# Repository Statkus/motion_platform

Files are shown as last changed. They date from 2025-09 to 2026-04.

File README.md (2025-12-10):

# Motion platform

Motion platform for simracing and flight simulation

## Servo motor driver parameters

Pn001: 4
Pn002: 2
Pn003: 0
Pn008: 300
Pn009: -300
Pn024: 10
Pn051: 3000
Pn052: 1 or -1 depending of how emergency stop is wired
Pn060: 2
Pn061: 6
Pn098: 10
Pn109: 1
Pn110: 30
Pn113: 20
Pn114: 10
Pn115: 100

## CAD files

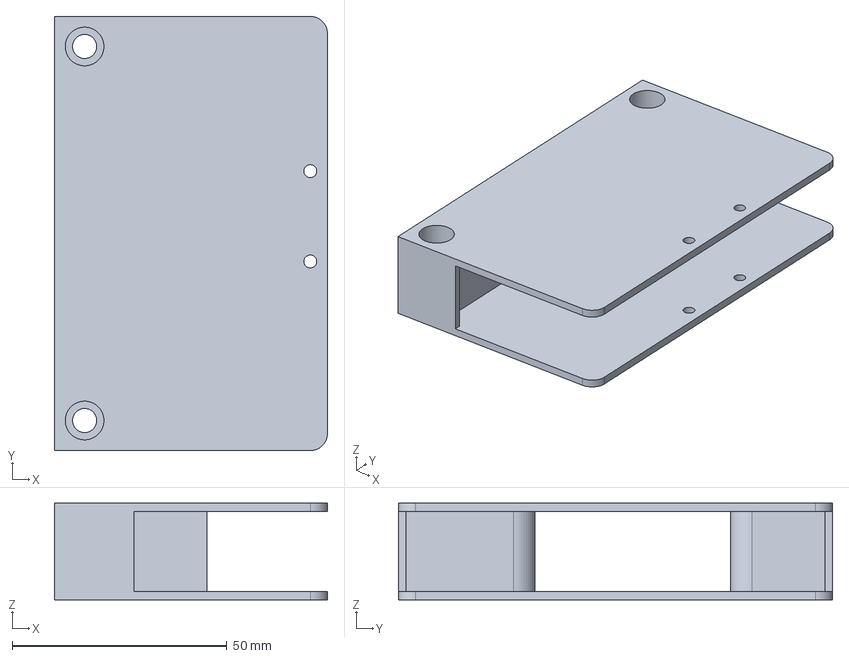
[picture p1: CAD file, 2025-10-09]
hardware/electrical_panel/main_breaker_mount.FCStd
63.5 x 101.0 x 22.5 mm

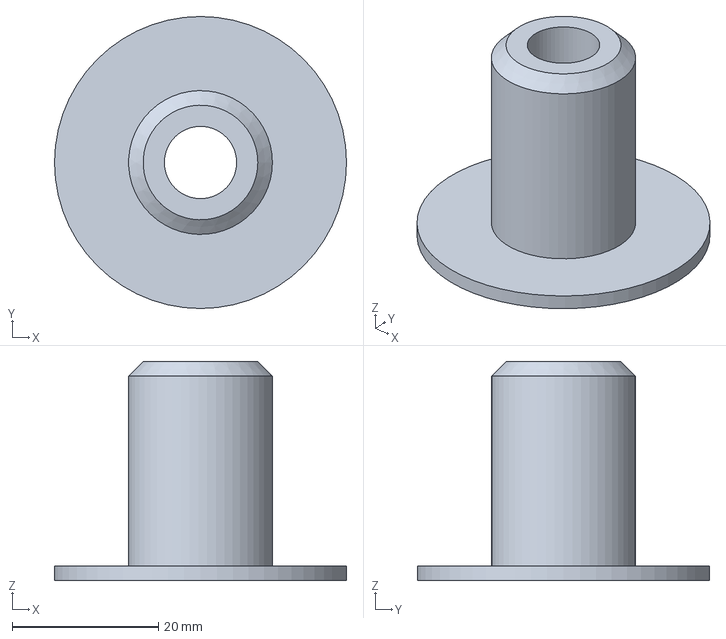
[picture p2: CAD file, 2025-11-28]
hardware/base_platform/3DOF_foot.FCStd
40.0 x 40.0 x 30.0 mm

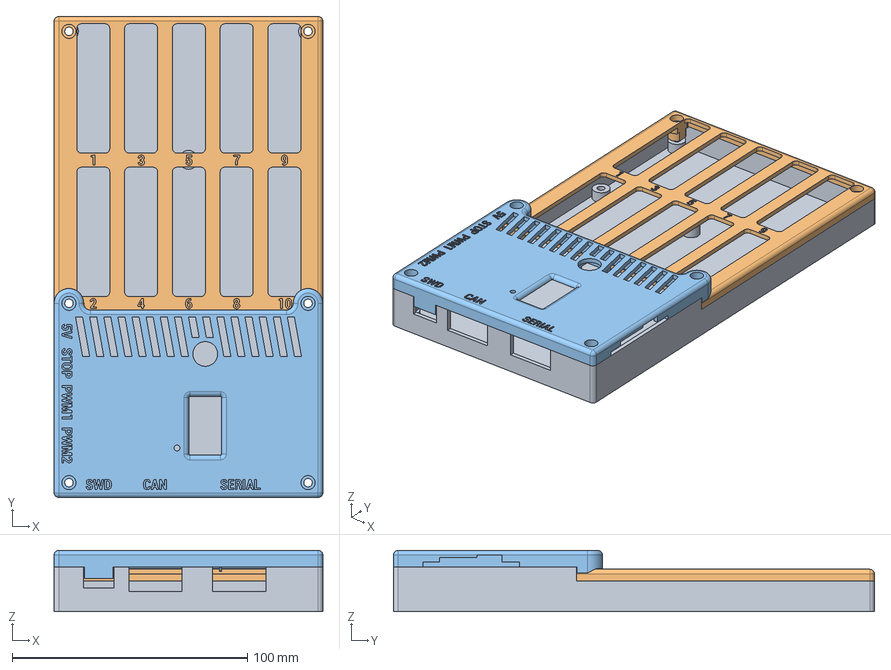
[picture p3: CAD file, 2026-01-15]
hardware/electrical_panel/control_box.FCStd
114.2 x 204.4 x 26.0 mm
Bottom
Top_DB25_text
Top_IC_text

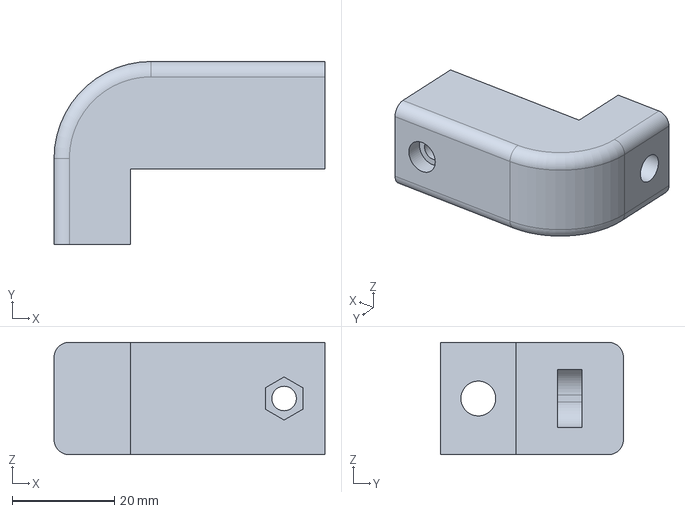
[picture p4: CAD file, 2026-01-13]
hardware/parts_library/pulley_to_SH25.FCStd
53.0 x 35.8 x 22.0 mm

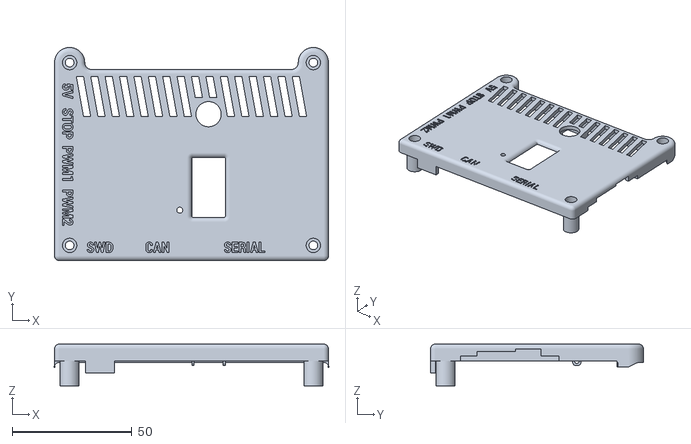
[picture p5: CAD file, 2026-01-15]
hardware/stl_files_to_print/control_box-Top_IC_text.stl
114.2 x 88.8 x 17.4

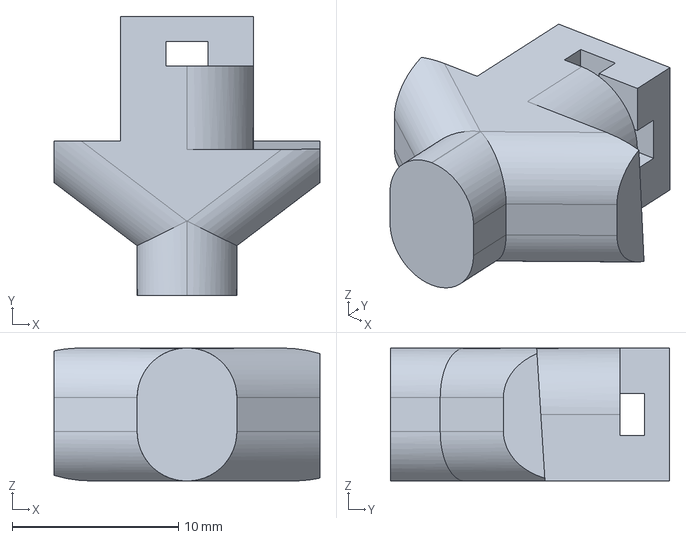
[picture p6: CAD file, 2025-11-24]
hardware/parts_library/zip_tie_2x1_mm_to_4040_profile.FCStd
16.0 x 16.8 x 8.00 mm

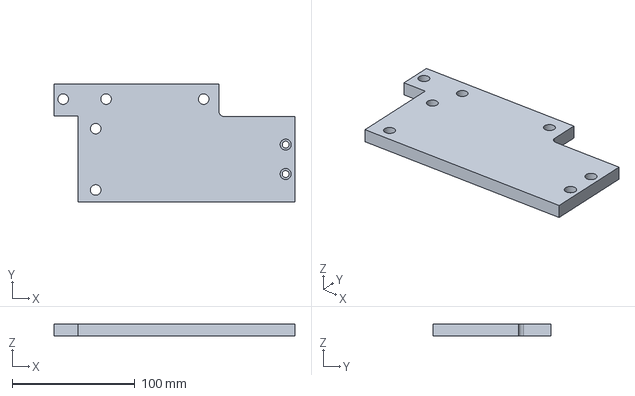
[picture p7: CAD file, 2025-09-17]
hardware/seat_mover/sway_motor_mount_rear_plate.FCStd
196.6 x 96.6 x 10.0 mm

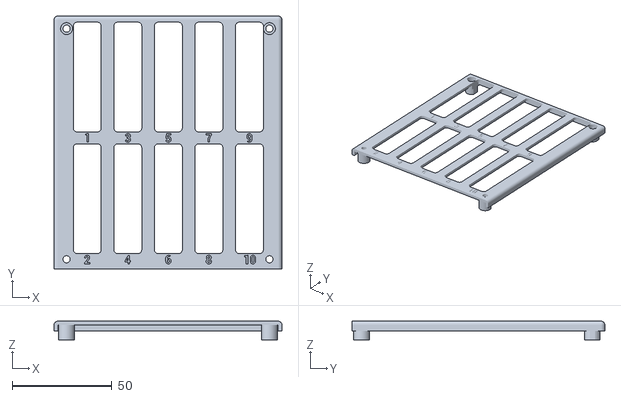
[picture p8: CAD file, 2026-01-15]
hardware/stl_files_to_print/control_box-Top_DB25_text.stl
114.2 x 126.7 x 9.40

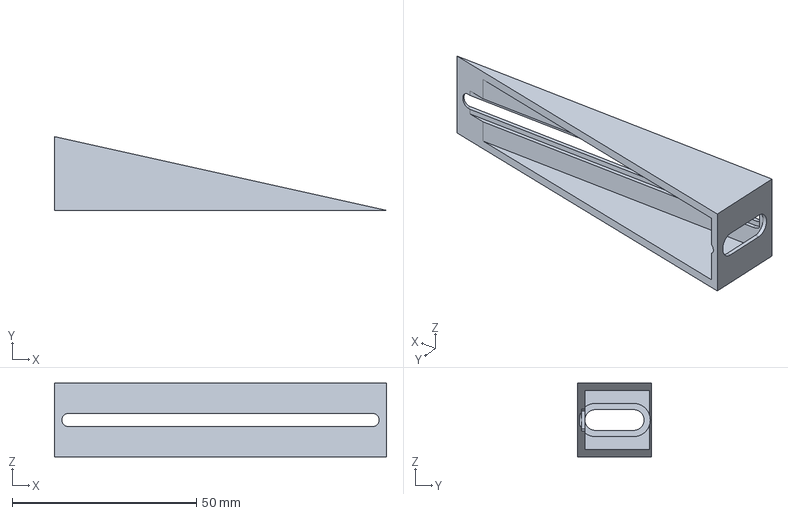
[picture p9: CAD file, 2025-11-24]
hardware/parts_library/2020_corner_bracket_M5_M3_long.FCStd
90.0 x 20.0 x 20.0 mm

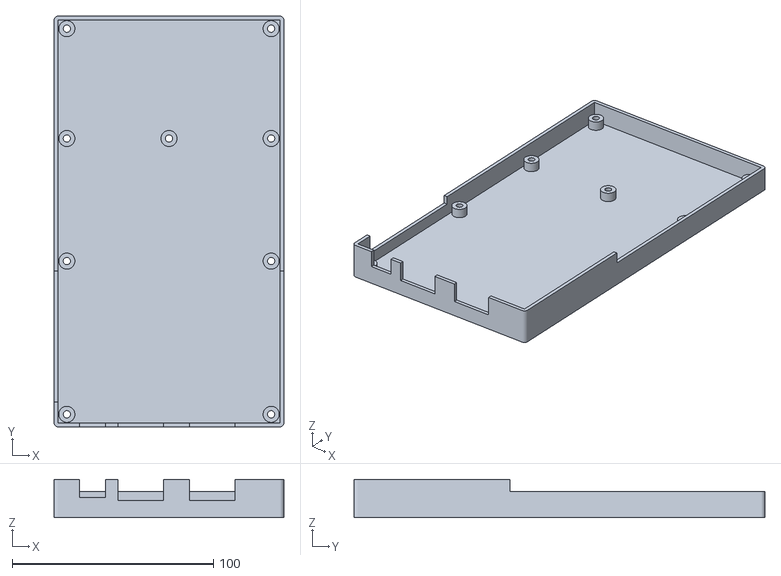
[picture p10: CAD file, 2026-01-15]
hardware/stl_files_to_print/control_box-Bottom.stl
114.2 x 204.4 x 19.0

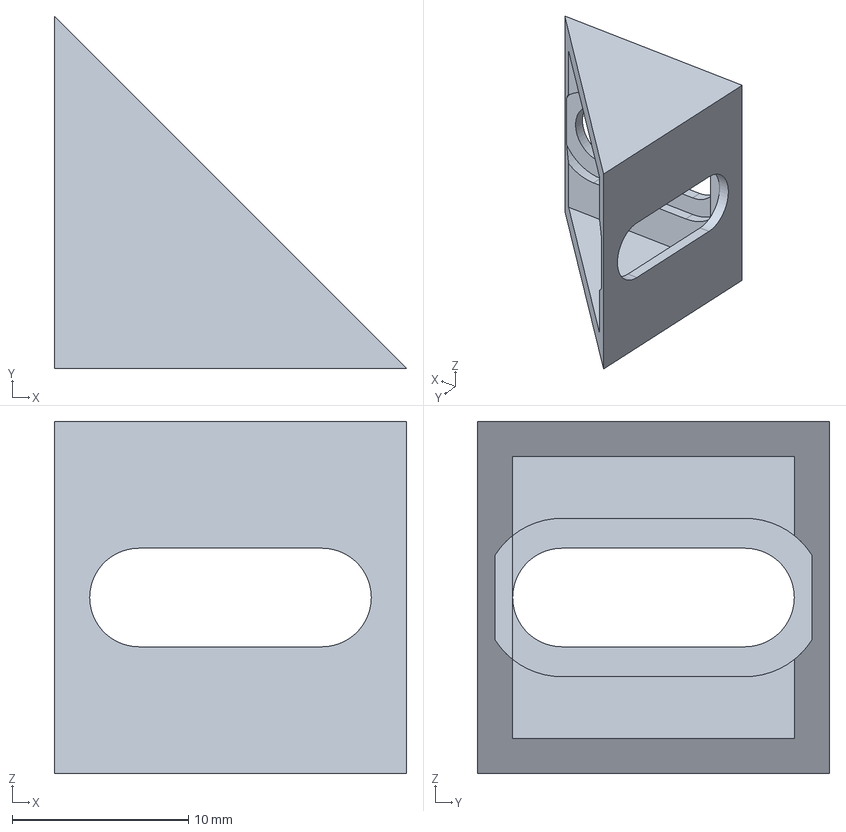
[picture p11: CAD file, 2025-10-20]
hardware/parts_library/2020_corner_bracket_M5.FCStd
20.0 x 20.0 x 20.0 mm

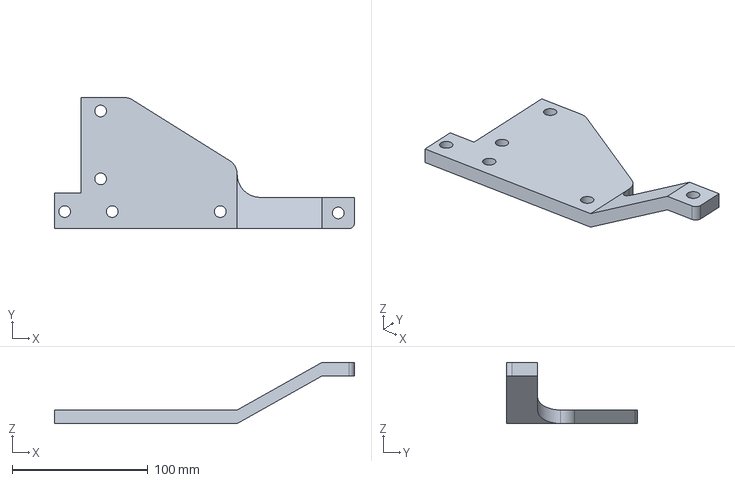
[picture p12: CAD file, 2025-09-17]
hardware/seat_mover/sway_motor_mount_front_plate.FCStd
221.0 x 96.6 x 45.0 mm

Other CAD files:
hardware/final_assembly.FCStd
hardware/stl_files_to_print/main_breaker_mount.stl
hardware/seat_mover/seat_mover.FCStd
hardware/base_platform/base_platform.FCStd
hardware/seat_mover/sway_platform.FCStd
hardware/stl_files_to_print/pulley_to_SH25.stl
hardware/parts_library/2020_corner_bracket_M5_M3.FCStd
hardware/parts_library/DSG16H_to_SH25.FCStd
hardware/parts_library/DSG16H_to_profile_40x40.FCStd
hardware/parts_library/SC25UU.FCStd
hardware/parts_library/SC25UU_to_SH25.FCStd
hardware/parts_library/SFU1605.FCStd
hardware/parts_library/SH25.FCStd
hardware/parts_library/SHF25.FCStd
hardware/parts_library/corner_bracket_40x40.FCStd
hardware/parts_library/coupler.FCStd
hardware/parts_library/linear_shaft.FCStd
hardware/parts_library/motor.FCStd
hardware/parts_library/profile_40_serie.FCStd
hardware/parts_library/zip_tie_2x1_mm_to_2020_profile.FCStd
hardware/seat_mover/seat.FCStd
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

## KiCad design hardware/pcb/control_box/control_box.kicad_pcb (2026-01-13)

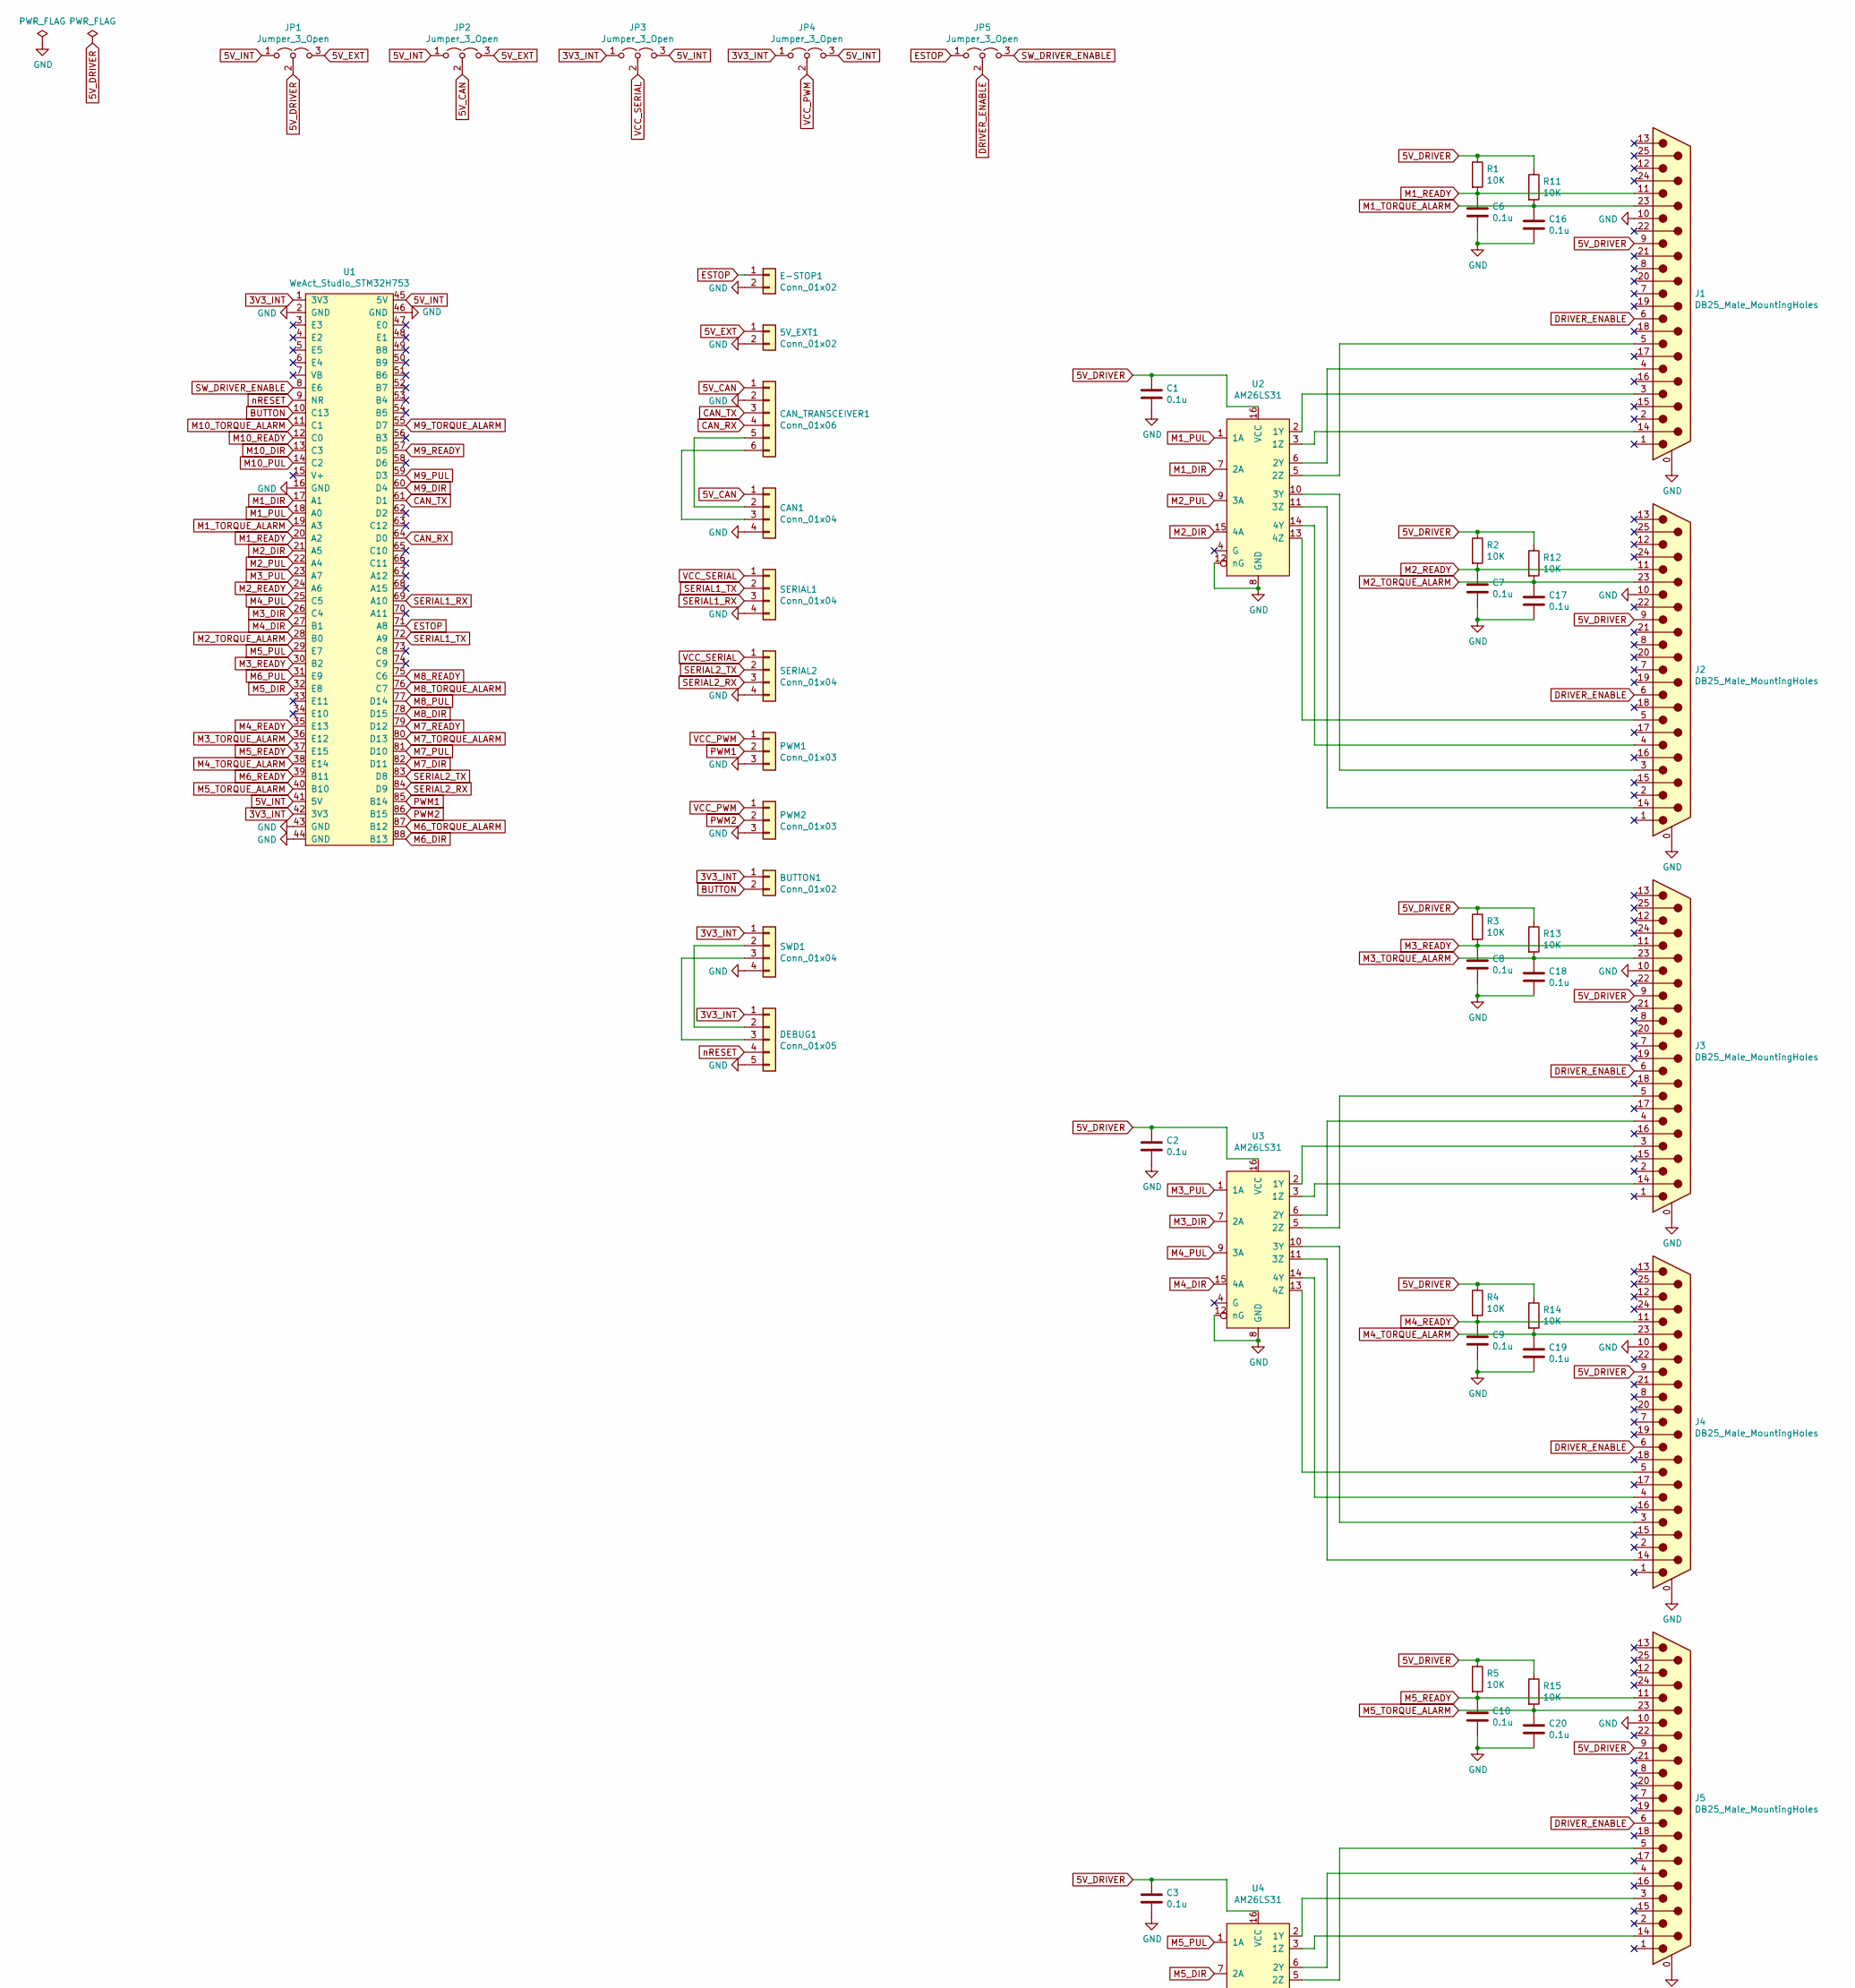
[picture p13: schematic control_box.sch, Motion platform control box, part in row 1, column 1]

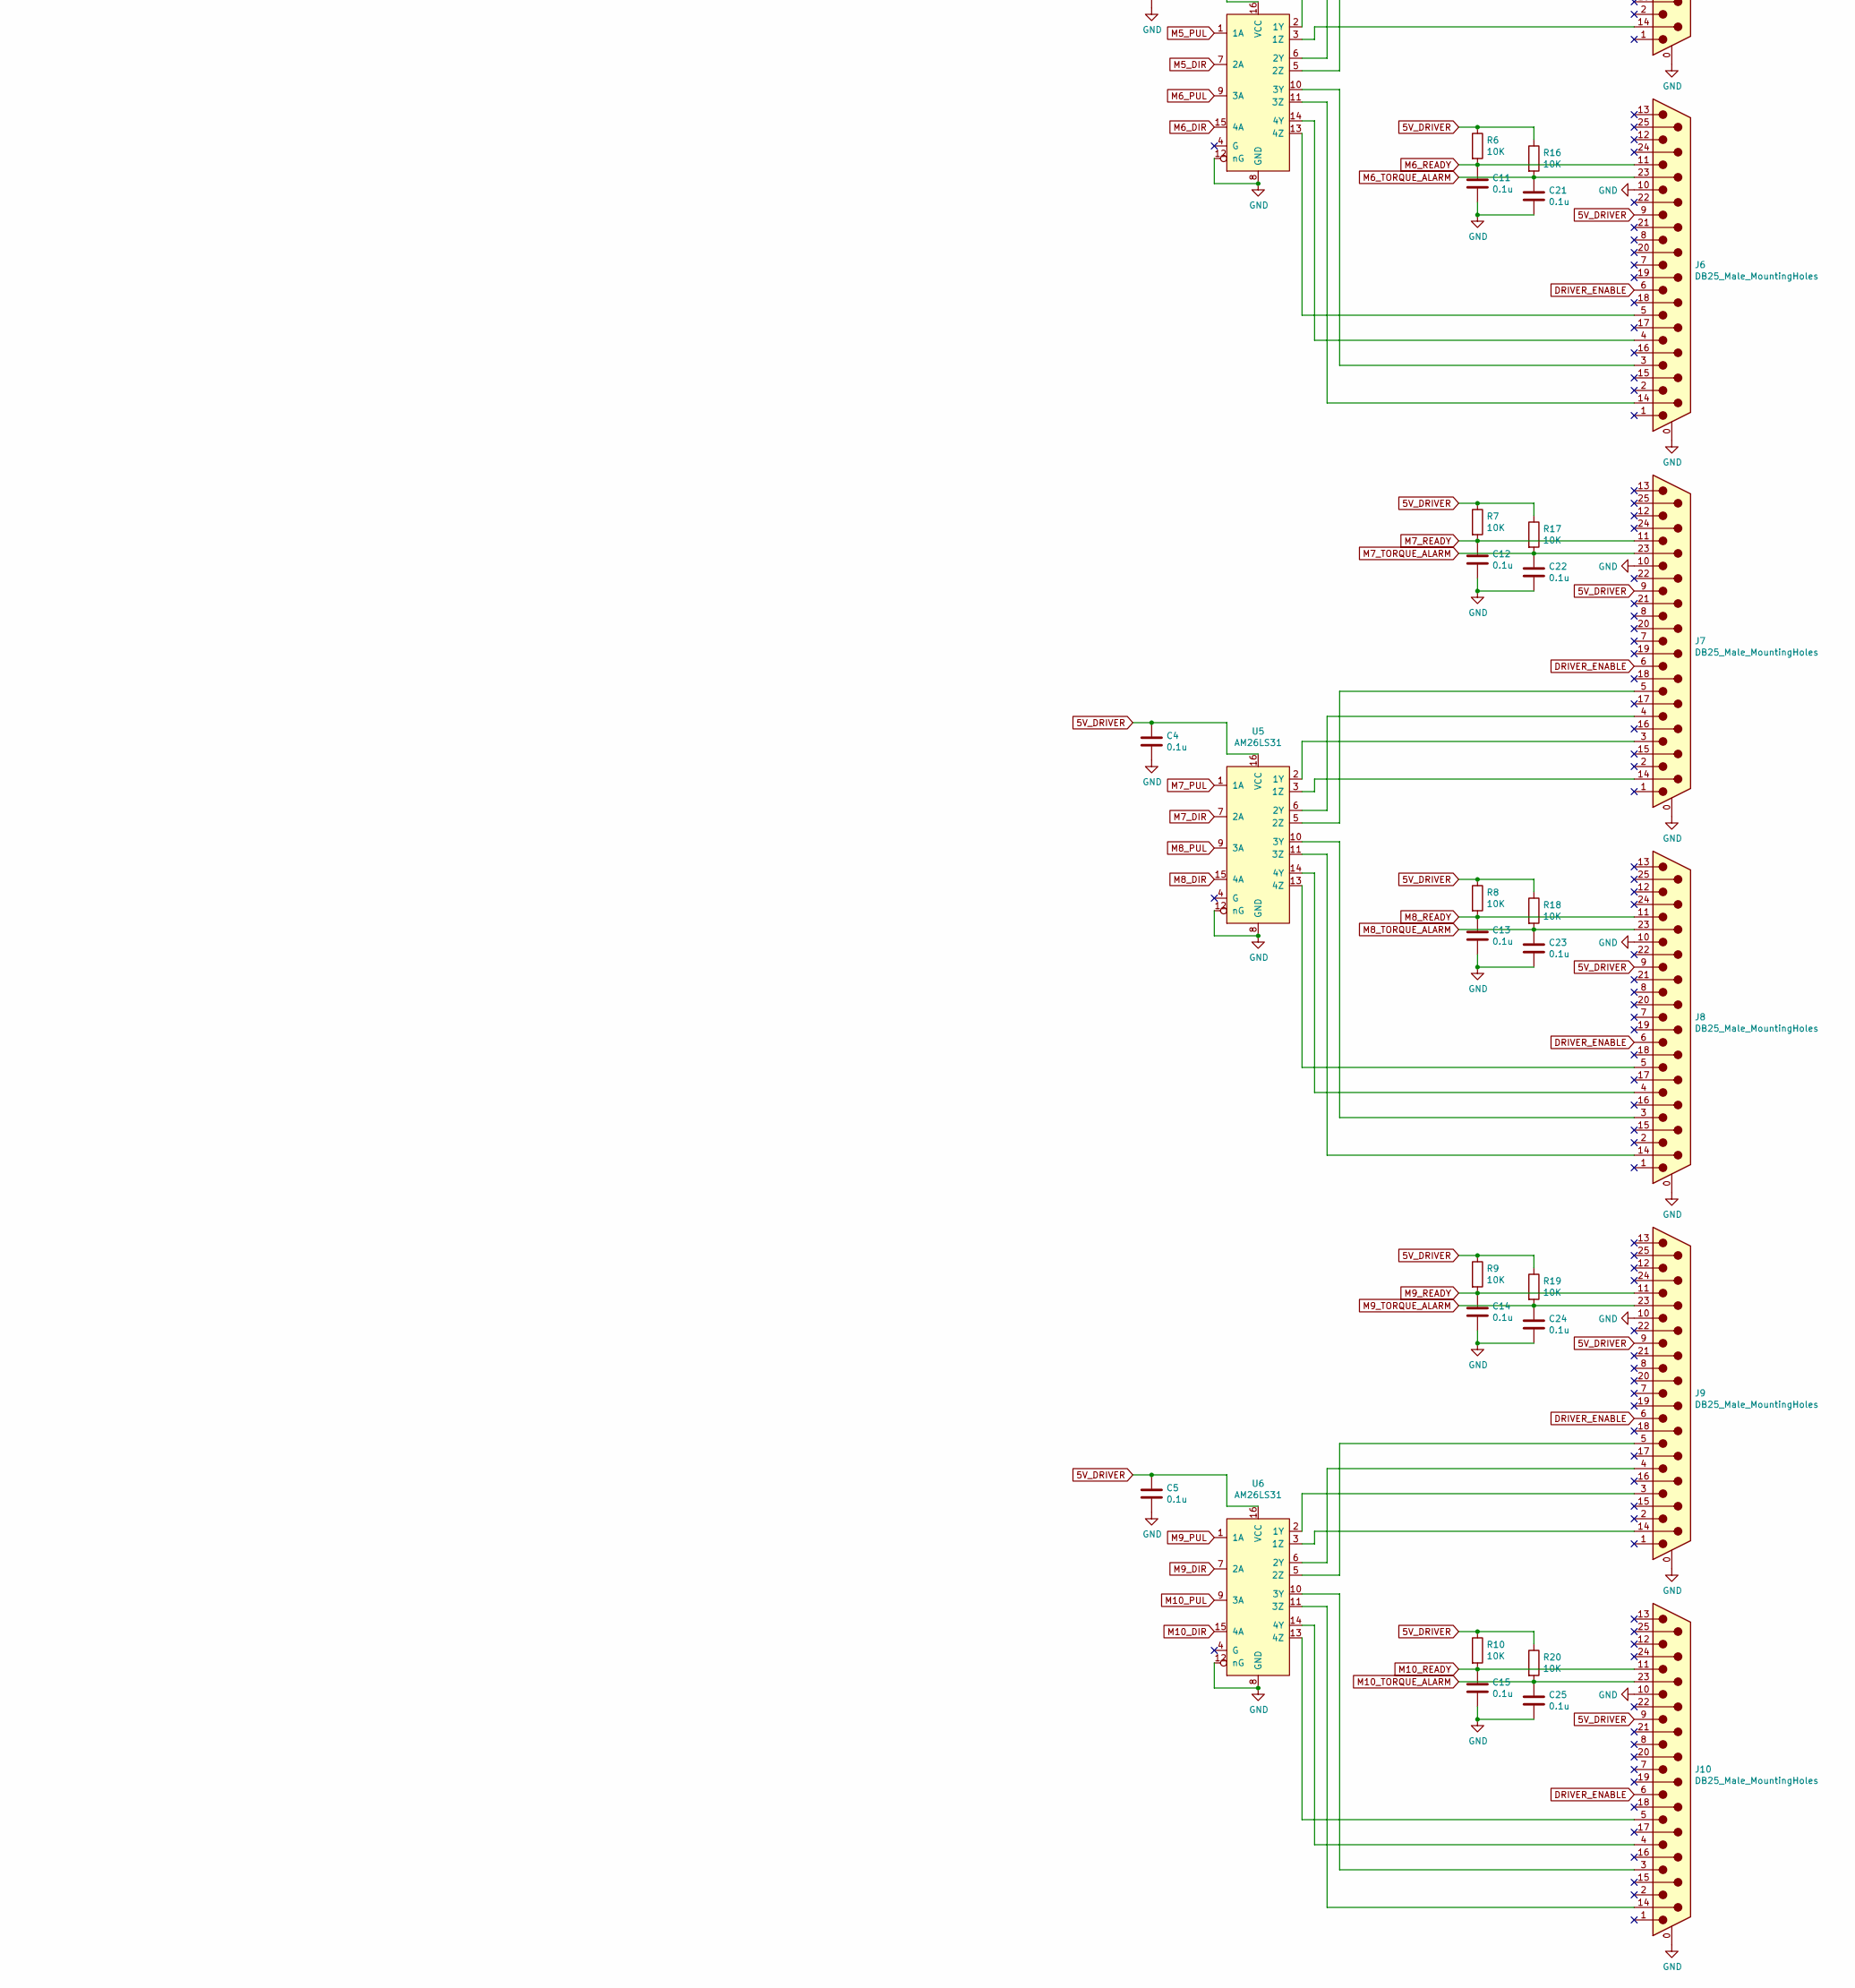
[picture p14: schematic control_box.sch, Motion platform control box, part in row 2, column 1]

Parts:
5V_EXT1: Conn_01x02; PhoenixContact_MSTBA_2,5_2-G-5,08_1x02_P5.08mm_Horizontal
BUTTON1: Conn_01x02; PinHeader_1x02_P2.54mm_Vertical
C1, C2, C3, C4, C5, C6, C7, C8, C9, C10, C11, C12, C13, C14, C15, C16, C17, C18, C19, C20, C21, C22, C23, C24, C25: 0.1u; C_Disc_D4.3mm_W1.9mm_P5.00mm
CAN1: Conn_01x04; PhoenixContact_MSTBA_2,5_4-G-5,08_1x04_P5.08mm_Horizontal
CAN_TRANSCEIVER1: Conn_01x06; PinHeader_1x06_P2.54mm_Vertical
DEBUG1: Conn_01x05; PinHeader_1x05_P2.54mm_Horizontal
E-STOP1: Conn_01x02; PhoenixContact_MSTBA_2,5_2-G-5,08_1x02_P5.08mm_Horizontal
J1, J2, J3, J4, J5, J6, J7, J8, J9, J10: DB25_Male_MountingHoles; DSUB-25_Female_Vertical_P2.77x2.84mm_MountingHoles
JP1, JP2, JP3, JP4, JP5: Jumper_3_Open; PinHeader_1x03_P2.54mm_Vertical
PWM1, PWM2: Conn_01x03; PhoenixContact_MSTBA_2,5_3-G-5,08_1x03_P5.08mm_Horizontal
R1, R2, R3, R4, R5, R6, R7, R8, R9, R10, R11, R12, R13, R14, R15, R16, R17, R18, R19, R20: 10K; R_Axial_DIN0204_L3.6mm_D1.6mm_P2.54mm_Vertical
SERIAL1: Conn_01x04; PinHeader_1x04_P2.54mm_Vertical
SERIAL2: Conn_01x04; PhoenixContact_MSTBA_2,5_4-G-5,08_1x04_P5.08mm_Horizontal
SWD1: Conn_01x04; PinHeader_1x04_P2.54mm_Vertical
U1: WeAct_Studio_STM32H753; WeAct_Studio_STM32H743
U2, U3, U4, U5, U6: AM26LS31; DIP-16_W7.62mm

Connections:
3V3_INT: BUTTON1.1, DEBUG1.1, JP3.1 (A), JP4.1 (A), SWD1.1, U1.1 (3V3), U1.42 (3V3)
5V_CAN: CAN1.1, CAN_TRANSCEIVER1.1, JP2.2 (C)
5V_DRIVER: C1.1, C2.1, C3.1, C4.1, C5.1, J1.9, J2.9, J3.9, J4.9, J5.9, J6.9, J7.9, J8.9, J9.9, J10.9, JP1.2 (C), R1.1, R2.1, R3.1, R4.1, R5.1, R6.1, R7.1, R8.1, R9.1, R10.1, R11.1, R12.1, R13.1, R14.1, R15.1, R16.1, R17.1, R18.1, R19.1, R20.1, U2.16 (VCC), U3.16 (VCC), U4.16 (VCC), U5.16 (VCC), U6.16 (VCC)
5V_EXT: 5V_EXT1.1, JP1.3 (B), JP2.3 (B)
5V_INT: JP1.1 (A), JP2.1 (A), JP3.3 (B), JP4.3 (B), U1.41 (5V), U1.45 (5V)
BUTTON: BUTTON1.2, U1.10 (C13)
CAN_RX: CAN_TRANSCEIVER1.4, U1.64 (D0)
CAN_TX: CAN_TRANSCEIVER1.3, U1.61 (D1)
DRIVER_ENABLE: J1.6, J2.6, J3.6, J4.6, J5.6, J6.6, J7.6, J8.6, J9.6, J10.6, JP5.2 (C)
ESTOP: E-STOP1.1, JP5.1 (A), U1.71 (A8)
GND: 5V_EXT1.2, C1.2, C2.2, C3.2, C4.2, C5.2, C6.2, C7.2, C8.2, C9.2, C10.2, C11.2, C12.2, C13.2, C14.2, C15.2, C16.2, C17.2, C18.2, C19.2, C20.2, C21.2, C22.2, C23.2, C24.2, C25.2, CAN1.4, CAN_TRANSCEIVER1.2, DEBUG1.5, E-STOP1.2, J1.0 (PAD), J1.10, J2.0 (PAD), J2.10, J3.0 (PAD), J3.10, J4.0 (PAD), J4.10, J5.0 (PAD), J5.10, J6.0 (PAD), J6.10, J7.0 (PAD), J7.10, J8.0 (PAD), J8.10, J9.0 (PAD), J9.10, J10.0 (PAD), J10.10, PWM1.3, PWM2.3, SERIAL1.4, SERIAL2.4, SWD1.4, U1.2 (GND), U1.16 (GND), U1.43 (GND), U1.44 (GND), U1.46 (GND), U2.8 (GND), U2.12 (nG), U3.8 (GND), U3.12 (nG), U4.8 (GND), U4.12 (nG), U5.8 (GND), U5.12 (nG), U6.8 (GND), U6.12 (nG)
M1_DIR: U1.17 (A1), U2.7 (2A)
M1_PUL: U1.18 (A0), U2.1 (1A)
M1_READY: C6.1, J1.11, R1.2, U1.20 (A2)
M1_TORQUE_ALARM: C16.1, J1.23, R11.2, U1.19 (A3)
M2_DIR: U1.21 (A5), U2.15 (4A)
M2_PUL: U1.22 (A4), U2.9 (3A)
M2_READY: C7.1, J2.11, R2.2, U1.24 (A6)
M2_TORQUE_ALARM: C17.1, J2.23, R12.2, U1.28 (B0)
M3_DIR: U1.26 (C4), U3.7 (2A)
M3_PUL: U1.23 (A7), U3.1 (1A)
M3_READY: C8.1, J3.11, R3.2, U1.30 (B2)
M3_TORQUE_ALARM: C18.1, J3.23, R13.2, U1.36 (E12)
M4_DIR: U1.27 (B1), U3.15 (4A)
M4_PUL: U1.25 (C5), U3.9 (3A)
M4_READY: C9.1, J4.11, R4.2, U1.35 (E13)
M4_TORQUE_ALARM: C19.1, J4.23, R14.2, U1.38 (E14)
M5_DIR: U1.32 (E8), U4.7 (2A)
M5_PUL: U1.29 (E7), U4.1 (1A)
M5_READY: C10.1, J5.11, R5.2, U1.37 (E15)
M5_TORQUE_ALARM: C20.1, J5.23, R15.2, U1.40 (B10)
M6_DIR: U1.88 (B13), U4.15 (4A)
M6_PUL: U1.31 (E9), U4.9 (3A)
M6_READY: C11.1, J6.11, R6.2, U1.39 (B11)
M6_TORQUE_ALARM: C21.1, J6.23, R16.2, U1.87 (B12)
M7_DIR: U1.82 (D11), U5.7 (2A)
M7_PUL: U1.81 (D10), U5.1 (1A)
M7_READY: C12.1, J7.11, R7.2, U1.79 (D12)
M7_TORQUE_ALARM: C22.1, J7.23, R17.2, U1.80 (D13)
M8_DIR: U1.78 (D15), U5.15 (4A)
M8_PUL: U1.77 (D14), U5.9 (3A)
M8_READY: C13.1, J8.11, R8.2, U1.75 (C6)
M8_TORQUE_ALARM: C23.1, J8.23, R18.2, U1.76 (C7)
M9_DIR: U1.60 (D4), U6.7 (2A)
M9_PUL: U1.59 (D3), U6.1 (1A)
M9_READY: C14.1, J9.11, R9.2, U1.57 (D5)
M9_TORQUE_ALARM: C24.1, J9.23, R19.2, U1.55 (D7)
M10_DIR: U1.13 (C3), U6.15 (4A)
M10_PUL: U1.14 (C2), U6.9 (3A)
M10_READY: C15.1, J10.11, R10.2, U1.12 (C0)
M10_TORQUE_ALARM: C25.1, J10.23, R20.2, U1.11 (C1)
unnamed: CAN1.2, CAN_TRANSCEIVER1.5
unnamed: CAN1.3, CAN_TRANSCEIVER1.6
unnamed: DEBUG1.2, SWD1.2
unnamed: DEBUG1.3, SWD1.3
unnamed: J1.3, U2.2 (1Y)
unnamed: J1.4, U2.6 (2Y)
unnamed: J1.5, U2.5 (2Z)
unnamed: J1.14, U2.3 (1Z)
unnamed: J2.3, U2.10 (3Y)
unnamed: J2.4, U2.14 (4Y)
unnamed: J2.5, U2.13 (4Z)
unnamed: J2.14, U2.11 (3Z)
unnamed: J3.3, U3.2 (1Y)
unnamed: J3.4, U3.6 (2Y)
unnamed: J3.5, U3.5 (2Z)
unnamed: J3.14, U3.3 (1Z)
unnamed: J4.3, U3.10 (3Y)
unnamed: J4.4, U3.14 (4Y)
unnamed: J4.5, U3.13 (4Z)
unnamed: J4.14, U3.11 (3Z)
unnamed: J5.3, U4.2 (1Y)
unnamed: J5.4, U4.6 (2Y)
unnamed: J5.5, U4.5 (2Z)
unnamed: J5.14, U4.3 (1Z)
unnamed: J6.3, U4.10 (3Y)
unnamed: J6.4, U4.14 (4Y)
unnamed: J6.5, U4.13 (4Z)
unnamed: J6.14, U4.11 (3Z)
unnamed: J7.3, U5.2 (1Y)
unnamed: J7.4, U5.6 (2Y)
unnamed: J7.5, U5.5 (2Z)
unnamed: J7.14, U5.3 (1Z)
unnamed: J8.3, U5.10 (3Y)
unnamed: J8.4, U5.14 (4Y)
unnamed: J8.5, U5.13 (4Z)
unnamed: J8.14, U5.11 (3Z)
unnamed: J9.3, U6.2 (1Y)
unnamed: J9.4, U6.6 (2Y)
unnamed: J9.5, U6.5 (2Z)
unnamed: J9.14, U6.3 (1Z)
unnamed: J10.3, U6.10 (3Y)
unnamed: J10.4, U6.14 (4Y)
unnamed: J10.5, U6.13 (4Z)
unnamed: J10.14, U6.11 (3Z)
PWM1: PWM1.2, U1.85 (B14)
PWM2: PWM2.2, U1.86 (B15)
SERIAL1_RX: SERIAL1.3, U1.69 (A10)
SERIAL1_TX: SERIAL1.2, U1.72 (A9)
SERIAL2_RX: SERIAL2.3, U1.84 (D9)
SERIAL2_TX: SERIAL2.2, U1.83 (D8)
SW_DRIVER_ENABLE: JP5.3 (B), U1.8 (E6)
VCC_PWM: JP4.2 (C), PWM1.1, PWM2.1
VCC_SERIAL: JP3.2 (C), SERIAL1.1, SERIAL2.1
nRESET: DEBUG1.4, U1.9 (NR)

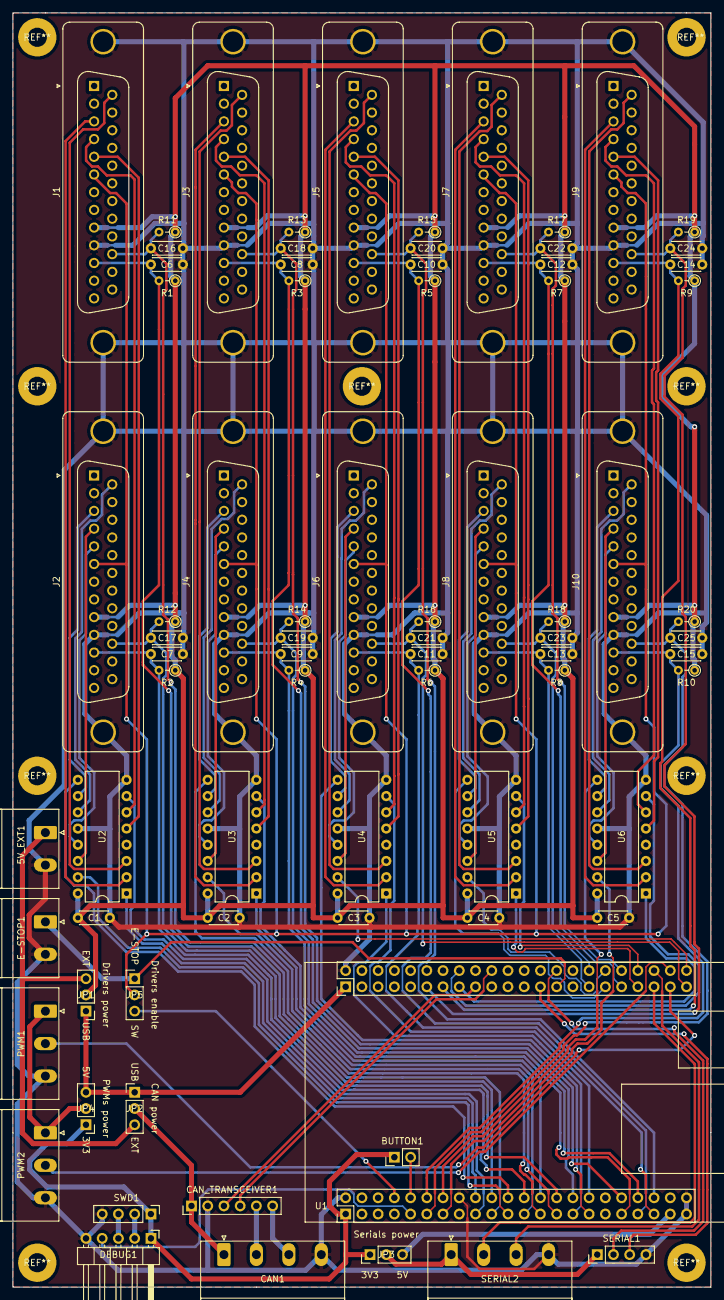
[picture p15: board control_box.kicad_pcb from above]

Board: 2 copper layers, 109.2 x 199.4 mm, 77 parts (0 on the bottom side), 105 nets.

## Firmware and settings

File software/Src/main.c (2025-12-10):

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
/* Includes ------------------------------------------------------------------*/
#include "main.h"
#include "usb_device.h"

/* USER CODE BEGIN Includes */

#include "motion_platform_configuration.h"
#include "usbd_cdc_if.h"

/* USER CODE END Includes */

/* USER CODE BEGIN PTD */

typedef struct
{
  GPIO_TypeDef *Port;
  uint16_t Pin;
} GPIO;

typedef struct
{
  GPIO Pulse_GPIO;
  GPIO Direction_GPIO;
  GPIO Ready_GPIO;
  GPIO Torque_Alarm_GPIO;

  int32_t Position;
  uint8_t Position_Zero_Centered;
  int32_t Min_Position;
  int32_t Max_Position;
  int32_t Target_Position;
  GPIO_PinState Direction;

  uint8_t Needs_Calibration;
  uint8_t Min_Position_Calibrated;
  uint8_t Max_Position_Calibrated;
} Motor;

typedef enum
{
  Initialization,
  Calibrate_Min_Position,
  Calibrate_Max_Position,
  Run
} State;

/* USER CODE END PTD */


TIM_HandleTypeDef htim3;
TIM_HandleTypeDef htim12;

/* USER CODE BEGIN PV */

Motor motors[NB_MOTORS] = {
  /* Motor 1 -----------------------------------------------------------------*/
  {.Pulse_GPIO =
    {.Port = M1_PUL_GPIO_Port,
     .Pin  = M1_PUL_Pin},
   .Direction_GPIO =
    {.Port = M1_DIR_GPIO_Port,
     .Pin  = M1_DIR_Pin},
   .Ready_GPIO =
    {.Port = M1_READY_GPIO_Port,
     .Pin  = M1_READY_Pin},
   .Torque_Alarm_GPIO =
    {.Port = M1_TORQUE_ALARM_GPIO_Port,
     .Pin  = M1_TORQUE_ALARM_Pin},

   .Position               = 0,
   .Position_Zero_Centered = M1_POSITION_ZERO_CENTERED,
   .Min_Position           = M1_MIN_POSITION,
   .Max_Position           = M1_MAX_POSITION,
   .Target_Position        = 0,
   .Direction              = GPIO_PIN_RESET,

   .Needs_Calibration       = M1_NEEDS_CALIBRATION,
   .Min_Position_Calibrated = 0,
   .Max_Position_Calibrated = 0},

  /* Motor 2 -----------------------------------------------------------------*/
  {.Pulse_GPIO =
    {.Port = M2_PUL_GPIO_Port,
     .Pin  = M2_PUL_Pin},
   .Direction_GPIO =
    {.Port = M2_DIR_GPIO_Port,
     .Pin  = M2_DIR_Pin},
   .Ready_GPIO =
    {.Port = M2_READY_GPIO_Port,
     .Pin  = M2_READY_Pin},
   .Torque_Alarm_GPIO =
    {.Port = M2_TORQUE_ALARM_GPIO_Port,
     .Pin  = M2_TORQUE_ALARM_Pin},

   .Position               = 0,
   .Position_Zero_Centered = M2_POSITION_ZERO_CENTERED,
   .Min_Position           = M2_MIN_POSITION,
   .Max_Position           = M2_MAX_POSITION,
   .Target_Position        = 0,
   .Direction              = GPIO_PIN_RESET,

   .Needs_Calibration       = M2_NEEDS_CALIBRATION,
   .Min_Position_Calibrated = 0,
   .Max_Position_Calibrated = 0},

  /* Motor 3 -----------------------------------------------------------------*/
  {.Pulse_GPIO =
    {.Port = M3_PUL_GPIO_Port,
     .Pin  = M3_PUL_Pin},
   .Direction_GPIO =
    {.Port = M3_DIR_GPIO_Port,
     .Pin  = M3_DIR_Pin},
   .Ready_GPIO =
    {.Port = M3_READY_GPIO_Port,
     .Pin  = M3_READY_Pin},
   .Torque_Alarm_GPIO =
    {.Port = M3_TORQUE_ALARM_GPIO_Port,
     .Pin  = M3_TORQUE_ALARM_Pin},

   .Position               = 0,
   .Position_Zero_Centered = M3_POSITION_ZERO_CENTERED,
   .Min_Position           = M3_MIN_POSITION,
   .Max_Position           = M3_MAX_POSITION,
   .Target_Position        = 0,
   .Direction              = GPIO_PIN_RESET,

   .Needs_Calibration       = M3_NEEDS_CALIBRATION,
   .Min_Position_Calibrated = 0,
   .Max_Position_Calibrated = 0},

  /* Motor 4 -----------------------------------------------------------------*/
  {.Pulse_GPIO =
    {.Port = M4_PUL_GPIO_Port,
     .Pin  = M4_PUL_Pin},
   .Direction_GPIO =
    {.Port = M4_DIR_GPIO_Port,
     .Pin  = M4_DIR_Pin},
   .Ready_GPIO =
    {.Port = M4_READY_GPIO_Port,
     .Pin  = M4_READY_Pin},
   .Torque_Alarm_GPIO =
    {.Port = M4_TORQUE_ALARM_GPIO_Port,
     .Pin  = M4_TORQUE_ALARM_Pin},

   .Position               = 0,
   .Position_Zero_Centered = M4_POSITION_ZERO_CENTERED,
   .Min_Position           = M4_MIN_POSITION,
   .Max_Position           = M4_MAX_POSITION,
   .Target_Position        = 0,
   .Direction              = GPIO_PIN_RESET,

   .Needs_Calibration       = M4_NEEDS_CALIBRATION,
   .Min_Position_Calibrated = 0,
   .Max_Position_Calibrated = 0},

  /* Motor 5 -----------------------------------------------------------------*/
  {.Pulse_GPIO =
    {.Port = M5_PUL_GPIO_Port,
     .Pin  = M5_PUL_Pin},
   .Direction_GPIO =
    {.Port = M5_DIR_GPIO_Port,
     .Pin  = M5_DIR_Pin},
   .Ready_GPIO =
    {.Port = M5_READY_GPIO_Port,
     .Pin  = M5_READY_Pin},
   .Torque_Alarm_GPIO =
    {.Port = M5_TORQUE_ALARM_GPIO_Port,
     .Pin  = M5_TORQUE_ALARM_Pin},

   .Position               = 0,
   .Position_Zero_Centered = M5_POSITION_ZERO_CENTERED,
   .Min_Position           = M5_MIN_POSITION,
   .Max_Position           = M5_MAX_POSITION,
   .Target_Position        = 0,
   .Direction              = GPIO_PIN_RESET,

   .Needs_Calibration       = M5_NEEDS_CALIBRATION,
   .Min_Position_Calibrated = 0,
   .Max_Position_Calibrated = 0},

  /* Motor 6 -----------------------------------------------------------------*/
  {.Pulse_GPIO =
    {.Port = M6_PUL_GPIO_Port,
     .Pin  = M6_PUL_Pin},
   .Direction_GPIO =
    {.Port = M6_DIR_GPIO_Port,
     .Pin  = M6_DIR_Pin},
   .Ready_GPIO =
    {.Port = M6_READY_GPIO_Port,
     .Pin  = M6_READY_Pin},
   .Torque_Alarm_GPIO =
    {.Port = M6_TORQUE_ALARM_GPIO_Port,
     .Pin  = M6_TORQUE_ALARM_Pin},

   .Position               = 0,
   .Position_Zero_Centered = M6_POSITION_ZERO_CENTERED,
   .Min_Position           = M6_MIN_POSITION,
   .Max_Position           = M6_MAX_POSITION,
   .Target_Position        = 0,
   .Direction              = GPIO_PIN_RESET,

   .Needs_Calibration       = M6_NEEDS_CALIBRATION,
   .Min_Position_Calibrated = 0,
   .Max_Position_Calibrated = 0},
};

int32_t m_speed        = 0; // step/s
int32_t m_target_speed = 0; // step/s

/* USER CODE END PV */

void SystemClock_Config(void);
static void MPU_Config(void);
static void MX_GPIO_Init(void);
static void MX_TIM3_Init(void);
static void MX_TIM12_Init(void);
/* USER CODE BEGIN PFP */

void Receive_Commands(void);
void Move_Motors_To_Min_Position(void);
void Move_Motors_To_Max_Position(void);
void Move_Motors_To_Target(void);
void Delay_Us(uint16_t us);

/* USER CODE END PFP */

/**
  * @brief  The application entry point.
  * @retval int
  */
int main(void)
{

  /* MPU Configuration--------------------------------------------------------*/
  MPU_Config();

  /* MCU Configuration--------------------------------------------------------*/

  /* Reset of all peripherals, Initializes the Flash interface and the Systick. */
  HAL_Init();

  /* Configure the system clock */
  SystemClock_Config();

  /* Initialize all configured peripherals */
  MX_GPIO_Init();
  MX_TIM3_Init();
  MX_USB_DEVICE_Init();
  MX_TIM12_Init();
  /* USER CODE BEGIN 2 */

  State state = Initialization;

  for (int i = 0; i < NB_MOTORS; i++) {
    motors[i].Direction = GPIO_PIN_RESET;

    HAL_GPIO_WritePin(motors[i].Pulse_GPIO.Port, motors[i].Pulse_GPIO.Pin, GPIO_PIN_SET);
    HAL_GPIO_WritePin(motors[i].Direction_GPIO.Port, motors[i].Direction_GPIO.Pin, motors[i].Direction);
  }

  HAL_TIM_Base_Start(&htim3);

  HAL_TIM_PWM_Start(&htim12, TIM_CHANNEL_1);
  HAL_TIM_PWM_Start(&htim12, TIM_CHANNEL_2);

  __HAL_TIM_SET_COMPARE(&htim12, TIM_CHANNEL_1, 500);
  __HAL_TIM_SET_COMPARE(&htim12, TIM_CHANNEL_2, 0);

  /* USER CODE END 2 */

  /* Infinite loop */
  /* USER CODE BEGIN WHILE */
  while (1)
  {
    /* USER CODE END WHILE */

    /* USER CODE BEGIN 3 */

    switch (state)
    {
      case Initialization:
      {
        uint8_t motors_ready = 1;

        for (int i = 0; i < NB_MOTORS; i++)
        {
          if (HAL_GPIO_ReadPin(motors[i].Ready_GPIO.Port, motors[i].Ready_GPIO.Pin) == GPIO_PIN_SET)
          {
            motors_ready = 0;
          }
        }

        if (motors_ready > 0)
        {
          HAL_GPIO_WritePin(LED_GPIO_Port, LED_Pin, GPIO_PIN_SET);

          if (HAL_GPIO_ReadPin(BUTTON_GPIO_Port, BUTTON_Pin) == GPIO_PIN_SET)
          {
            state = Calibrate_Min_Position;
            HAL_GPIO_WritePin(LED_GPIO_Port, LED_Pin, GPIO_PIN_RESET);
          }
        }
        else
        {
          HAL_GPIO_WritePin(LED_GPIO_Port, LED_Pin, GPIO_PIN_RESET);
        }

        break;
      }

      case Calibrate_Min_Position:
      {
        uint8_t needs_calibration = 0;

        for (int i = 0; i < NB_MOTORS; i++)
        {
          if (motors[i].Needs_Calibration > 0 && motors[i].Min_Position_Calibrated == 0)
          {
            if (HAL_GPIO_ReadPin(motors[i].Torque_Alarm_GPIO.Port, motors[i].Torque_Alarm_GPIO.Pin) == GPIO_PIN_RESET)
            {
              motors[i].Min_Position_Calibrated = 1;
              motors[i].Position                = 0;
              motors[i].Min_Position            = MIN_MAX_SAFETY_BUFFER;
              motors[i].Target_Position         = motors[i].Min_Position;
            }
            else
            {
              needs_calibration = 1;
            }
          }
        }

        if (needs_calibration > 0)
        {
          Move_Motors_To_Min_Position();
        }
        else
        {
          state = Calibrate_Max_Position;
        }

        break;
      }

      case Calibrate_Max_Position:
      {
        uint8_t needs_calibration = 0;

        for (int i = 0; i < NB_MOTORS; i++)
        {
          if (motors[i].Needs_Calibration > 0 && motors[i].Max_Position_Calibrated == 0)
          {
            if (HAL_GPIO_ReadPin(motors[i].Torque_Alarm_GPIO.Port, motors[i].Torque_Alarm_GPIO.Pin) == GPIO_PIN_RESET && motors[i].Position > motors[i].Min_Position)
            {
              motors[i].Max_Position_Calibrated = 1;
              motors[i].Max_Position            = motors[i].Position - MIN_MAX_SAFETY_BUFFER;

              if (motors[i].Position_Zero_Centered > 0)
              {
                motors[i].Min_Position    = (motors[i].Min_Position - motors[i].Max_Position) / 2;
                motors[i].Max_Position    = -motors[i].Min_Position;
                motors[i].Position        = motors[i].Max_Position + MIN_MAX_SAFETY_BUFFER;

                motors[i].Target_Position = 0;
              }
              else
              {
                motors[i].Target_Position = (motors[i].Max_Position - motors[i].Min_Position) / 2;
              }

              m_target_speed = M_MAX_SPEED / 2;
            }
            else
            {
              needs_calibration = 1;
            }
          }
        }

        if (needs_calibration > 0)
        {
          Move_Motors_To_Max_Position();
        }
        else
        {
          HAL_GPIO_WritePin(LED_GPIO_Port, LED_Pin, GPIO_PIN_SET);

          state = Run;
        }

        break;
      }

      case Run:
        Receive_Commands();

        Move_Motors_To_Target();

        break;
    }
  }
  /* USER CODE END 3 */
}

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
/* USER CODE BEGIN 4 */

void Receive_Commands(void)
{
  if (Is_New_Data() > 0)
  {
    HAL_GPIO_TogglePin(LED_GPIO_Port, LED_Pin);

    int32_t pos_target = 0;
    int32_t dist       = 0;
    int32_t max_dist   = 0;

    for (int i = 0; i < NB_MOTORS; i++)
    {
      pos_target = Get_M_Pos_Target(i);

      if (motors[i].Position_Zero_Centered > 0)
      {
        pos_target -= 32767;
      }

      motors[i].Target_Position =
       MIN(MAX(pos_target, motors[i].Min_Position), motors[i].Max_Position);

      dist = motors[i].Target_Position - motors[i].Position;

      if (abs(dist) > abs(max_dist))
      {
        max_dist = dist;
      }
    }

    m_target_speed = MAX(MIN((max_dist * 1000000) / MESSAGE_PERIOD_US, M_MAX_SPEED), -M_MAX_SPEED);

    __HAL_TIM_SET_COMPARE(&htim12, TIM_CHANNEL_1, 500 + (Get_Shaker_PWM() * 2));
    __HAL_TIM_SET_COMPARE(&htim12, TIM_CHANNEL_2, Get_Fan_PWM() * 4);
  }
}

void Move_Motors_To_Min_Position(void)
{
  uint8_t change_direction = 0;

  for (int i = 0; i < NB_MOTORS; i++)
  {
    if (motors[i].Needs_Calibration > 0 && motors[i].Min_Position_Calibrated == 0)
    {
      if (motors[i].Direction != GPIO_PIN_SET)
      {
        motors[i].Direction = GPIO_PIN_SET;

        HAL_GPIO_WritePin(motors[i].Direction_GPIO.Port, motors[i].Direction_GPIO.Pin, motors[i].Direction);

        change_direction = 1;
      }
    }
  }

  if (change_direction > 0)
  {
    Delay_Us(DIRECTION_DELAY_US);
  }

  uint8_t change_position = 0;

  for (int i = 0; i < NB_MOTORS; i++)
  {
    if (motors[i].Needs_Calibration > 0 && motors[i].Min_Position_Calibrated == 0)
    {
      change_position = 1;

      HAL_GPIO_WritePin(motors[i].Pulse_GPIO.Port, motors[i].Pulse_GPIO.Pin, GPIO_PIN_RESET);
    }
  }

  if (change_position > 0)
  {
    Delay_Us(PULSE_DOWN_DELAY_US);

    for (int i = 0; i < NB_MOTORS; i++)
    {
      if (motors[i].Needs_Calibration > 0 && motors[i].Min_Position_Calibrated == 0)
      {
        HAL_GPIO_WritePin(motors[i].Pulse_GPIO.Port, motors[i].Pulse_GPIO.Pin, GPIO_PIN_SET);
      }
    }

    Delay_Us(CALIBRATION_STEP_DELAY_US);
  }
}

void Move_Motors_To_Max_Position(void)
{
  uint8_t change_direction = 0;

  for (int i = 0; i < NB_MOTORS; i++)
  {
    if (motors[i].Needs_Calibration > 0 && motors[i].Max_Position_Calibrated == 0)
    {
      if (motors[i].Direction != GPIO_PIN_RESET)
      {
        motors[i].Direction = GPIO_PIN_RESET;

        HAL_GPIO_WritePin(motors[i].Direction_GPIO.Port, motors[i].Direction_GPIO.Pin, motors[i].Direction);

        change_direction = 1;
      }
    }
  }

  if (change_direction > 0)
  {
    Delay_Us(DIRECTION_DELAY_US);
  }

  uint8_t change_position = 0;

  for (int i = 0; i < NB_MOTORS; i++)
  {
    if (motors[i].Needs_Calibration > 0 && motors[i].Max_Position_Calibrated == 0)
    {
      change_position = 1;

      HAL_GPIO_WritePin(motors[i].Pulse_GPIO.Port, motors[i].Pulse_GPIO.Pin, GPIO_PIN_RESET);
    }
  }

  if (change_position > 0)
  {
    Delay_Us(PULSE_DOWN_DELAY_US);

    for (int i = 0; i < NB_MOTORS; i++)
    {
      if (motors[i].Needs_Calibration > 0 && motors[i].Max_Position_Calibrated == 0)
      {
        if (motors[i].Direction == GPIO_PIN_RESET)
        {
          motors[i].Position++;
        }
        else
        {
          motors[i].Position--;
        }

        HAL_GPIO_WritePin(motors[i].Pulse_GPIO.Port, motors[i].Pulse_GPIO.Pin, GPIO_PIN_SET);
      }
    }

    Delay_Us(CALIBRATION_STEP_DELAY_US);
  }
}

void Move_Motors_To_Target(void)
{
  uint8_t change_direction = 0;

  for (int i = 0; i < NB_MOTORS; i++)
  {
    if (motors[i].Position != motors[i].Target_Position)
    {
      const GPIO_PinState new_direction =
       (motors[i].Position < motors[i].Target_Position) ? GPIO_PIN_RESET : GPIO_PIN_SET;

      if (new_direction != motors[i].Direction)
      {
        motors[i].Direction = new_direction;

        HAL_GPIO_WritePin(motors[i].Direction_GPIO.Port, motors[i].Direction_GPIO.Pin, motors[i].Direction);

        change_direction = 1;
      }
    }
  }

  if (change_direction > 0)
  {
    Delay_Us(DIRECTION_DELAY_US);

    m_speed = 0;
  }

  uint8_t change_position = 0;

  for (int i = 0; i < NB_MOTORS; i++)
  {
    if (motors[i].Position != motors[i].Target_Position)
    {
      change_position = 1;

      HAL_GPIO_WritePin(motors[i].Pulse_GPIO.Port, motors[i].Pulse_GPIO.Pin, GPIO_PIN_RESET);
    }
  }

  if (change_position > 0)
  {
    Delay_Us(PULSE_DOWN_DELAY_US);

    for (int i = 0; i < NB_MOTORS; i++)
    {
      if (motors[i].Position != motors[i].Target_Position)
      {
        if (motors[i].Direction == GPIO_PIN_RESET)
        {
          motors[i].Position++;
        }
        else
        {
          motors[i].Position--;
        }

        HAL_GPIO_WritePin(motors[i].Pulse_GPIO.Port, motors[i].Pulse_GPIO.Pin, GPIO_PIN_SET);
      }
    }

    if (m_speed != m_target_speed)
    {
      int32_t error = m_target_speed - m_speed;

      if (abs(error) <= M_MAX_ACCELERATION)
      {
        m_speed = m_target_speed;
      }
      else
      {
        if (error > 0)
        {
          m_speed += M_MAX_ACCELERATION;
        }
        else
        {
          m_speed -= M_MAX_ACCELERATION;
        }
      }
    }

    if (m_speed != 0)
    {
      Delay_Us((uint16_t)(MIN(1000000 / abs(m_speed), MAX_SPEED_DELAY_US)));
    }
    else
    {
      Delay_Us(MAX_SPEED_DELAY_US);
    }

  }
  else
  {
    m_speed = 0;
  }
}

void Delay_Us (uint16_t us)
{
  __HAL_TIM_SET_COUNTER(&htim3, 0);
  while (__HAL_TIM_GET_COUNTER(&htim3) < us);
}

/* USER CODE END 4 */

 /* MPU Configuration */

void MPU_Config(void)
{
  MPU_Region_InitTypeDef MPU_InitStruct = {0};

  /* Disables the MPU */
  HAL_MPU_Disable();

  /** Initializes and configures the Region and the memory to be protected
  */
  MPU_InitStruct.Enable = MPU_REGION_ENABLE;
  MPU_InitStruct.Number = MPU_REGION_NUMBER0;
  MPU_InitStruct.BaseAddress = 0x0;
  MPU_InitStruct.Size = MPU_REGION_SIZE_4GB;
  MPU_InitStruct.SubRegionDisable = 0x87;
  MPU_InitStruct.TypeExtField = MPU_TEX_LEVEL0;
  MPU_InitStruct.AccessPermission = MPU_REGION_NO_ACCESS;
  MPU_InitStruct.DisableExec = MPU_INSTRUCTION_ACCESS_DISABLE;
  MPU_InitStruct.IsShareable = MPU_ACCESS_SHAREABLE;
  MPU_InitStruct.IsCacheable = MPU_ACCESS_NOT_CACHEABLE;
  MPU_InitStruct.IsBufferable = MPU_ACCESS_NOT_BUFFERABLE;

  HAL_MPU_ConfigRegion(&MPU_InitStruct);
  /* Enables the MPU */
  HAL_MPU_Enable(MPU_PRIVILEGED_DEFAULT);

}

/**
  * @brief  This function is executed in case of error occurrence.
  * @retval None
  */
void Error_Handler(void)
{
  /* USER CODE BEGIN Error_Handler_Debug */
  /* User can add his own implementation to report the HAL error return state */
  __disable_irq();
  while (1)
  {
  }
  /* USER CODE END Error_Handler_Debug */
}
#ifdef USE_FULL_ASSERT
/**
  * @brief  Reports the name of the source file and the source line number
  *         where the assert_param error has occurred.
  * @param  file: pointer to the source file name
  * @param  line: assert_param error line source number
  * @retval None
  */
void assert_failed(uint8_t *file, uint32_t line)
{
}
#endif /* USE_FULL_ASSERT */

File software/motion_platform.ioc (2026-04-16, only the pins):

Mcu.UserName=STM32H743VITx
PA0.GPIO_Label=M1_PUL
PA0.Signal=GPIO_Output
PA1.GPIO_Label=M1_DIR
PA1.Signal=GPIO_Output
PA10.GPIO_Label=SERIAL1_RX
PA10.Signal=USART1_RX
PA11.Signal=USB_OTG_FS_DM
PA12.Signal=USB_OTG_FS_DP
PA2.GPIO_Label=M1_READY
PA2.Signal=GPIO_Input
PA3.GPIO_Label=M1_TORQUE_ALARM
PA3.Signal=GPIO_Input
PA4.GPIO_Label=M2_PUL
PA4.Signal=GPIO_Output
PA5.GPIO_Label=M2_DIR
PA5.Signal=GPIO_Output
PA6.GPIO_Label=M2_READY
PA6.Signal=GPIO_Input
PA7.GPIO_Label=M3_PUL
PA7.Signal=GPIO_Output
PA8.GPIO_Label=ESTOP
PA8.Signal=GPIO_Input
PA9.GPIO_Label=SERIAL1_TX
PA9.Signal=USART1_TX
PB0.GPIO_Label=M2_TORQUE_ALARM
PB0.Signal=GPIO_Input
PB1.GPIO_Label=M4_DIR
PB1.Signal=GPIO_Output
PB10.GPIO_Label=M5_TORQUE_ALARM
PB10.Signal=GPIO_Input
PB11.GPIO_Label=M6_READY
PB11.Signal=GPIO_Input
PB12.GPIO_Label=M6_TORQUE_ALARM
PB12.Signal=GPIO_Input
PB13.GPIO_Label=M6_DIR
PB13.Signal=GPIO_Output
PB14.GPIO_Label=PWM1
PB14.Signal=S_TIM12_CH1
PB15.GPIO_Label=PWM2
PB15.Signal=S_TIM12_CH2
PB2.GPIO_Label=M3_READY
PB2.Signal=GPIO_Input
PB6.Signal=QUADSPI_BK1_NCS
PB8.Signal=I2C1_SCL
PB9.Signal=I2C1_SDA
PC0.GPIO_Label=M10_READY
PC0.Signal=GPIO_Input
PC1.GPIO_Label=M10_TORQUE_ALARM
PC1.Signal=GPIO_Input
PC10.Signal=SDMMC1_D2
PC11.Signal=SDMMC1_D3
PC12.Signal=SDMMC1_CK
PC13.GPIO_Label=BUTTON
PC13.Signal=GPIO_Input
PC2_C.GPIO_Label=M10_PUL
PC2_C.Signal=GPIO_Output
PC3_C.GPIO_Label=M10_DIR
PC3_C.Signal=GPIO_Output
PC4.GPIO_Label=M3_DIR
PC4.Signal=GPIO_Output
PC5.GPIO_Label=M4_PUL
PC5.Signal=GPIO_Output
PC6.GPIO_Label=M8_READY
PC6.Signal=GPIO_Input
PC7.GPIO_Label=M8_TORQUE_ALARM
PC7.Signal=GPIO_Input
PC8.Signal=SDMMC1_D0
PC9.Signal=SDMMC1_D1
PD0.GPIO_Label=CAN_RX
PD0.Signal=FDCAN1_RX
PD1.GPIO_Label=CAN_TX
PD1.Signal=FDCAN1_TX
PD10.GPIO_Label=M7_PUL
PD10.Signal=GPIO_Output
PD11.GPIO_Label=M7_DIR
PD11.Signal=GPIO_Output
PD12.GPIO_Label=M7_READY
PD12.Signal=GPIO_Input
PD13.GPIO_Label=M7_TORQUE_ALARM
PD13.Signal=GPIO_Input
PD14.GPIO_Label=M8_PUL
PD14.Signal=GPIO_Output
PD15.GPIO_Label=M8_DIR
PD15.Signal=GPIO_Output
PD2.Signal=SDMMC1_CMD
PD3.GPIO_Label=M9_PUL
PD3.Signal=GPIO_Output
PD4.GPIO_Label=M9_DIR
PD4.Signal=GPIO_Output
PD5.GPIO_Label=M9_READY
PD5.Signal=GPIO_Input
PD6.GPIO_Label=SPI_FLASH_CS
PD6.Signal=GPIO_Input
PD7.GPIO_Label=M9_TORQUE_ALARM
PD7.Signal=GPIO_Input
PD8.GPIO_Label=SERIAL2_TX
PD8.Signal=USART3_TX
PD9.GPIO_Label=SERIAL2_RX
PD9.Signal=USART3_RX
PE10.Signal=TIM1_CH2N
PE11.GPIO_Label=LCD_CS
PE11.Signal=GPIO_Input
PE12.GPIO_Label=M3_TORQUE_ALARM
PE12.Signal=GPIO_Input
PE13.GPIO_Label=M4_READY
PE13.Signal=GPIO_Input
PE14.GPIO_Label=M4_TORQUE_ALARM
PE14.Signal=GPIO_Input
PE15.GPIO_Label=M5_READY
PE15.Signal=GPIO_Input
PE3.GPIO_Label=LED
PE3.Signal=GPIO_Output
PE6.GPIO_Label=SW_DRIVER_ENABLE
PE6.Signal=GPIO_Output
PE7.GPIO_Label=M5_PUL
PE7.Signal=GPIO_Output
PE8.GPIO_Label=M5_DIR
PE8.Signal=GPIO_Output
PE9.GPIO_Label=M6_PUL
PE9.Signal=GPIO_Output

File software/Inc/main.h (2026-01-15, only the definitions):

#define LED_Pin GPIO_PIN_3
#define LED_GPIO_Port GPIOE
#define BUTTON_Pin GPIO_PIN_13
#define BUTTON_GPIO_Port GPIOC
#define M1_PUL_Pin GPIO_PIN_0
#define M1_PUL_GPIO_Port GPIOA
#define M1_DIR_Pin GPIO_PIN_1
#define M1_DIR_GPIO_Port GPIOA
#define M1_READY_Pin GPIO_PIN_2
#define M1_READY_GPIO_Port GPIOA
#define M1_TORQUE_ALARM_Pin GPIO_PIN_3
#define M1_TORQUE_ALARM_GPIO_Port GPIOA
#define M2_PUL_Pin GPIO_PIN_4
#define M2_PUL_GPIO_Port GPIOA
#define M2_DIR_Pin GPIO_PIN_5
#define M2_DIR_GPIO_Port GPIOA
#define M2_READY_Pin GPIO_PIN_6
#define M2_READY_GPIO_Port GPIOA
#define M3_PUL_Pin GPIO_PIN_7
#define M3_PUL_GPIO_Port GPIOA
#define M3_DIR_Pin GPIO_PIN_4
#define M3_DIR_GPIO_Port GPIOC
#define M4_PUL_Pin GPIO_PIN_5
#define M4_PUL_GPIO_Port GPIOC
#define M2_TORQUE_ALARM_Pin GPIO_PIN_0
#define M2_TORQUE_ALARM_GPIO_Port GPIOB
#define M4_DIR_Pin GPIO_PIN_1
#define M4_DIR_GPIO_Port GPIOB
#define M3_READY_Pin GPIO_PIN_2
#define M3_READY_GPIO_Port GPIOB
#define M5_PUL_Pin GPIO_PIN_7
#define M5_PUL_GPIO_Port GPIOE
#define M5_DIR_Pin GPIO_PIN_8
#define M5_DIR_GPIO_Port GPIOE
#define M6_PUL_Pin GPIO_PIN_9
#define M6_PUL_GPIO_Port GPIOE
#define LCD_CS_Pin GPIO_PIN_11
#define LCD_CS_GPIO_Port GPIOE
#define M3_TORQUE_ALARM_Pin GPIO_PIN_12
#define M3_TORQUE_ALARM_GPIO_Port GPIOE
#define M4_READY_Pin GPIO_PIN_13
#define M4_READY_GPIO_Port GPIOE
#define M4_TORQUE_ALARM_Pin GPIO_PIN_14
#define M4_TORQUE_ALARM_GPIO_Port GPIOE
#define M5_READY_Pin GPIO_PIN_15
#define M5_READY_GPIO_Port GPIOE
#define M5_TORQUE_ALARM_Pin GPIO_PIN_10
#define M5_TORQUE_ALARM_GPIO_Port GPIOB
#define M6_READY_Pin GPIO_PIN_11
#define M6_READY_GPIO_Port GPIOB
#define M6_TORQUE_ALARM_Pin GPIO_PIN_12
#define M6_TORQUE_ALARM_GPIO_Port GPIOB
#define M6_DIR_Pin GPIO_PIN_13
#define M6_DIR_GPIO_Port GPIOB
#define SHAKER_PWM_Pin GPIO_PIN_14
#define SHAKER_PWM_GPIO_Port GPIOB
#define FAN_PWM_Pin GPIO_PIN_15
#define FAN_PWM_GPIO_Port GPIOB
#define SPI_FLASH_CS_Pin GPIO_PIN_6
#define SPI_FLASH_CS_GPIO_Port GPIOD
#define DIRECTION_DELAY_US        5
#define PULSE_DOWN_DELAY_US       5
#define CALIBRATION_STEP_DELAY_US 300
#define MAX_SPEED_DELAY_US        1000
#define MIN_MAX_SAFETY_BUFFER 1000 // step
#define M_MAX_SPEED        40000 // step/s     // 40000 pour un comportement comme avant
#define M_MAX_ACCELERATION 2000  // step/s^2

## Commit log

2025-08-28 [3D] Add 3D parts library
    [DSG16H_to_SH25.FCStd, DSG16H_to_profile_40x40.FCStd, SC25UU.FCStd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]
2025-08-28 [3D] Add base platform
    [base_platform.FCStd]
2025-09-17 [3D] Add seat mover surge platform
    [surge_BK12_mount_bottom.FCStd, surge_BK12_mount_top.FCStd, surge_BK12_support.FCStd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]
2025-09-17 [3D] Add seat mover sway platform
    [sway_SC25UU_to_SH25_with_plate.FCStd, sway_motor_mount_bottom.FCStd, sway_motor_mount_front_plate.FCStd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]
2025-09-17 [3D] Add seat mover seat platform
    [seat.FCStd, seat_platform.FCStd]
2025-09-17 [3D] Add seat mover assembly
    [seat_mover.FCStd]
2025-09-17 [3D] Add final assembly
    [final_assembly.FCStd]
2025-09-17 [3D] Add exported STL files to print
    [DSG16H_to_SH25.stl, DSG16H_to_profile_40x40.stl, SC25UU_to_SH25.stl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]
2025-09-22 [BUILD] Add OpenOCD configuration file for STM32H743
2025-09-23 [DEV] Add homing behavior
2025-09-23 [DOC] Add servo motor driver parameters value to change
2025-10-09 [DEV] Improve motors calibration
2025-10-09 [3D] Add main breaker mount for electrical panel
    [main_breaker_mount.FCStd]
2025-10-09 [3D] Add parts for 2020 profile
    [2020_corner_bracket_M5_M3.FCStd, zip_tie_2x1_mm_to_2020_profile.FCStd]
2025-10-09 [GEN] Update generated code
    Update STM32CubeMX and firmware version and add GPIO for 6 motors
2025-10-20 [3D] Add corner bracket for M5 on 2020 profile
    [2020_corner_bracket_M5.FCStd, 2020_corner_bracket_M5.stl]
2025-10-22 [DEV] Use integer type for motors position
2025-11-24 [3D] Add corner bracket for M5/M3 on 2020 profile with long side
    [2020_corner_bracket_M5_M3_long.FCStd, 2020_corner_bracket_M5_M3_long.stl]
2025-11-24 [3D] Add zip tie mount for 4040 profile
    [zip_tie_2x1_mm_to_4040_profile.FCStd, zip_tie_2x1_mm_to_4040_profile.stl]
2025-11-24 [BUILD] Print memory usage
2025-11-24 [DEV] Update to 6 motors
2025-11-28 [3D] Add foot for 3DOF base platform
    [3DOF_foot.FCStd, 3DOF_foot.stl]
2025-12-09 [DEV] Adjust motors max speed and acceleration
2025-12-10 [GEN] Update generated code to change GPIOs for fan and shaker
2025-12-10 [DEV] Update timer used for fan and shaker
2025-12-10 [DOC] Update servo driver parameters value
2026-01-13 [3D] Add pulley to tension harness in surge axis
    [pulley_to_SH25.FCStd, pulley_to_SH25.stl]
2026-01-13 [PCB] Add control box PCB KiCad design
    [control_box.kicad_pcb, control_box.sch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]
2026-01-15 [3D] Add control box case
    [control_box-Bottom.stl, control_box-Top_DB25_text.stl, control_box-Top_IC_text.stl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]
2026-01-15 [DEV] Reduce motors speed during calibration
2026-04-16 WIP new STM32CubeMX IOs

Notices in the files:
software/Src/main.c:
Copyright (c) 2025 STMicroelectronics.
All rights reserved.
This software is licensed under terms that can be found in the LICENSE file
